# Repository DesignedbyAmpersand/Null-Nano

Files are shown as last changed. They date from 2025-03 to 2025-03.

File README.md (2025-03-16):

The Null Nano is an ESP32 powered gaming handheld that uses retro-go from ducalex.

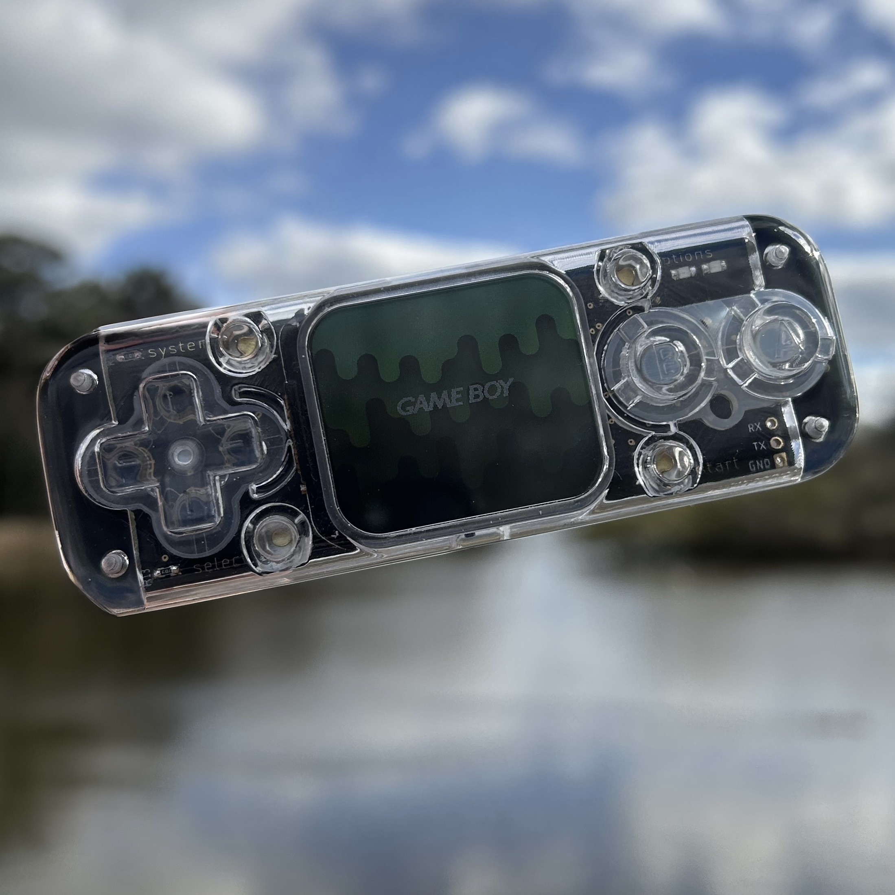
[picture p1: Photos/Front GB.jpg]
Front GB


It measures 100x35x15mm and has roughly 3 hours of battery life.

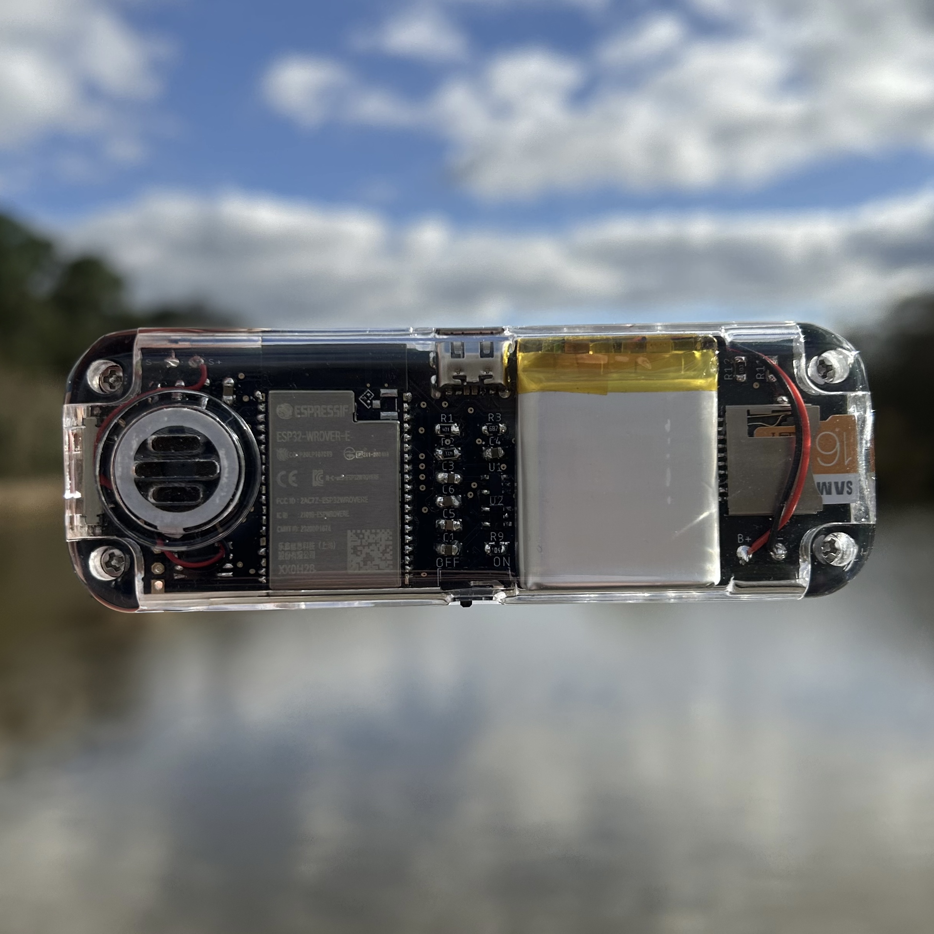
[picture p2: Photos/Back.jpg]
Back


This is not a beginner project.

These files are provided for free and with no guarantees.
These files are provided for personal use and not for resale purposes.

You will need the SD card skeleton files from here: https://1drv.ms/u/c/66cb300826c22fa3/Efv0uc86yZ5Hv4n83UHvBrcBqe-35vOahgP56gvEnUvf-g?e=ifL2Ww

You will also need the ESP32 flash download tool: https://1drv.ms/u/c/66cb300826c22fa3/EbNSYC88lTlOn8YUjpB1ucgBnk_qerDjQeKToj3xAFp3lw?e=woOXxG

Do not use a USB C to USB C cable to charge the Null Nano, it does not have anything connected to CC1 or CC2.

Do not use the Null Nano whilst charging, it does not have the necessary components to make this safe.

Use Kapton tape, do not use regular tape or masking tape.

You will need the latest version of the ESP flash tool to flash the Null Nano. Make sure you have installed the necessary drivers for your USB to UART adapter. The "options" button acts as a Boot button, so hold down options when you turn it on/provide power to enter bootloader mode for flashing.

The R3 resistor determines the charge rate. 1000/X = Y
e.g. for a 5.6K resistor the equation is 1000/5.6 = 179mA
If you use a different battery, you will need to change this resistor value.

The green LED goes on the right and the red LED on the left.

Trim the plastic pins off the bottom of the micro SD card socket with a scalpel or flush cutters (the holes needed would've interfered with the DPad).

The PCB needs to be 1.6mm thick. I order through JLCPCB and have "JLCJLCJLCJLC" written on the board so that the production number can be hidden below the ESP32.

The screws used are 8mm M2 self-tapping cap head

Resources used:

Odroid GO schematic
https://github.com/hardkernel/ODROID-GO/blob/master/Documents/ODROID-GO_REV0.1_20180518.pdf

Screen config file from this project
https://circuitdigest.com/microcontroller-projects/esp32-based-retro-game-console

Amp circuit based on Adafruit Class D amplifier
https://learn.adafruit.com/adafruit-pam8302-mono-2-5w-class-d-audio-amplifier

Charge circuit based on Adafruit MicroLiPo
https://learn.adafruit.com/adafruit-microlipo-and-minilipo-battery-chargers

Retro-go software
https://github.com/ducalex/retro-go

All graphics designed by me
The working title was "Wrigley" if you were wondering.

Let me know if you make one, have fun!
Ampersand

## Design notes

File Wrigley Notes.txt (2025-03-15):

Wrigley Notes

Wrigley is an ESP32 powered gaming handheld that uses retro-go from ducalex.
It measures 100x35x15mm and has roughly 3 hours of battery life.

This is not a beginner project.

These files are provided for free and with no guarantees.
These files are provided for personal use and not for resale purposes.

Do not use a USB C to USB C cable to charge Wrigley, it does not have anything connected to CC1 or CC2.

Do not use Wrigley whilst charging, it does not have the necessary components to make this safe.

Use Kapton tape, do not use regular tape or masking tape.

You will need the latest version of the ESP flash tool to flash Wrigley. Make sure you have installed the necessary drivers for your USB to UART adapter. The "options" button acts as a Boot button, so hold down options when you turn it on/provide power to enter bootloader mode for flashing.

The R3 resistor determines the charge rate. 1000/X = Y
e.g. for a 5.6K resistor the equation is 1000/5.6 = 179mA
If you use a different battery, you will need to change this resistor value.

The green LED goes on the right and the red LED on the left.

Trim the plastic pins off the bottom of the micro SD card socket with a scalpel or flush cutters (the holes needed would've interfered with the DPad).

The PCB needs to be 1.6mm thick. I order through JLCPCB and have "JLCJLCJLCJLC" written on the board so that the production number can be hidden below the ESP32.

The screws used are 8mm M2 self-tapping cap head

Resources used:

Odroid GO schematic
https://github.com/hardkernel/ODROID-GO/blob/master/Documents/ODROID-GO_REV0.1_20180518.pdf

Screen config file from this project
https://circuitdigest.com/microcontroller-projects/esp32-based-retro-game-console

Amp circuit based on Adafruit Class D amplifier
https://learn.adafruit.com/adafruit-pam8302-mono-2-5w-class-d-audio-amplifier

Charge circuit based on Adafruit MicroLiPo
https://learn.adafruit.com/adafruit-microlipo-and-minilipo-battery-chargers

Retro-go software
https://github.com/ducalex/retro-go

All graphics designed by me

Let me know if you make one, have fun!
Ampersand

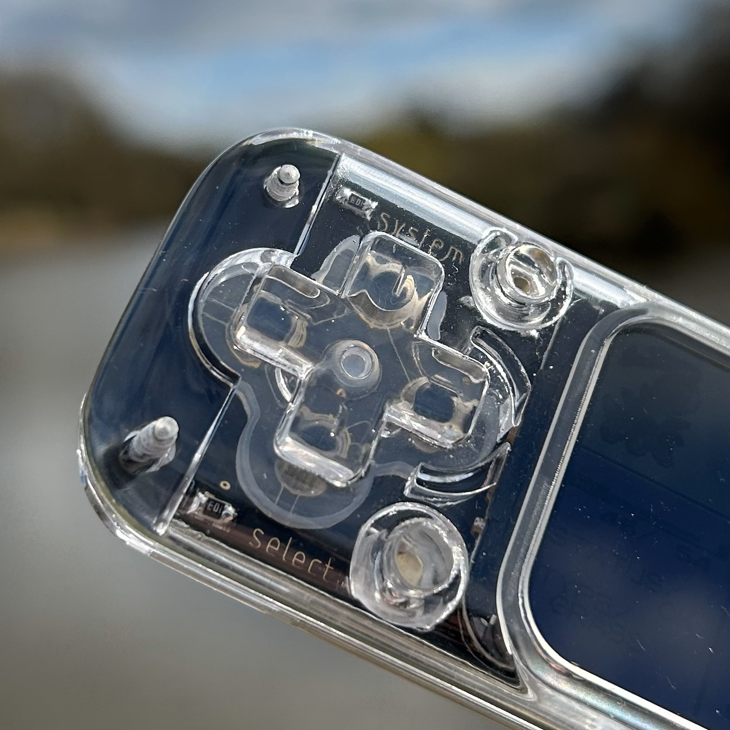
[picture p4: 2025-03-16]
Photos/Close up left.png

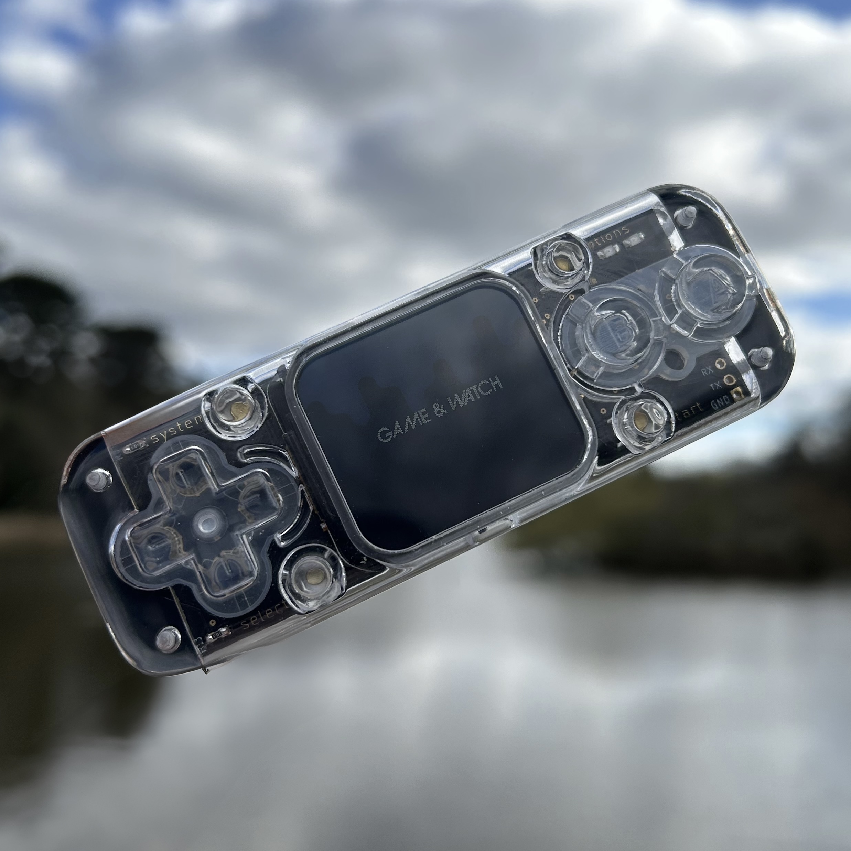
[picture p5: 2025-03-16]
Photos/Front GW.jpg

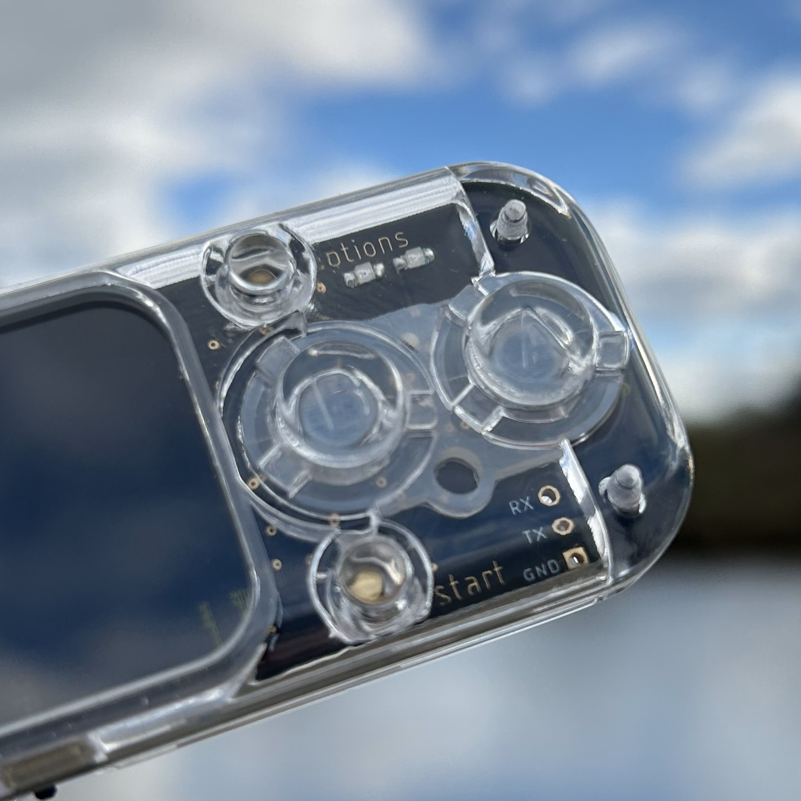
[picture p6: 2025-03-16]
Photos/Close up right.png

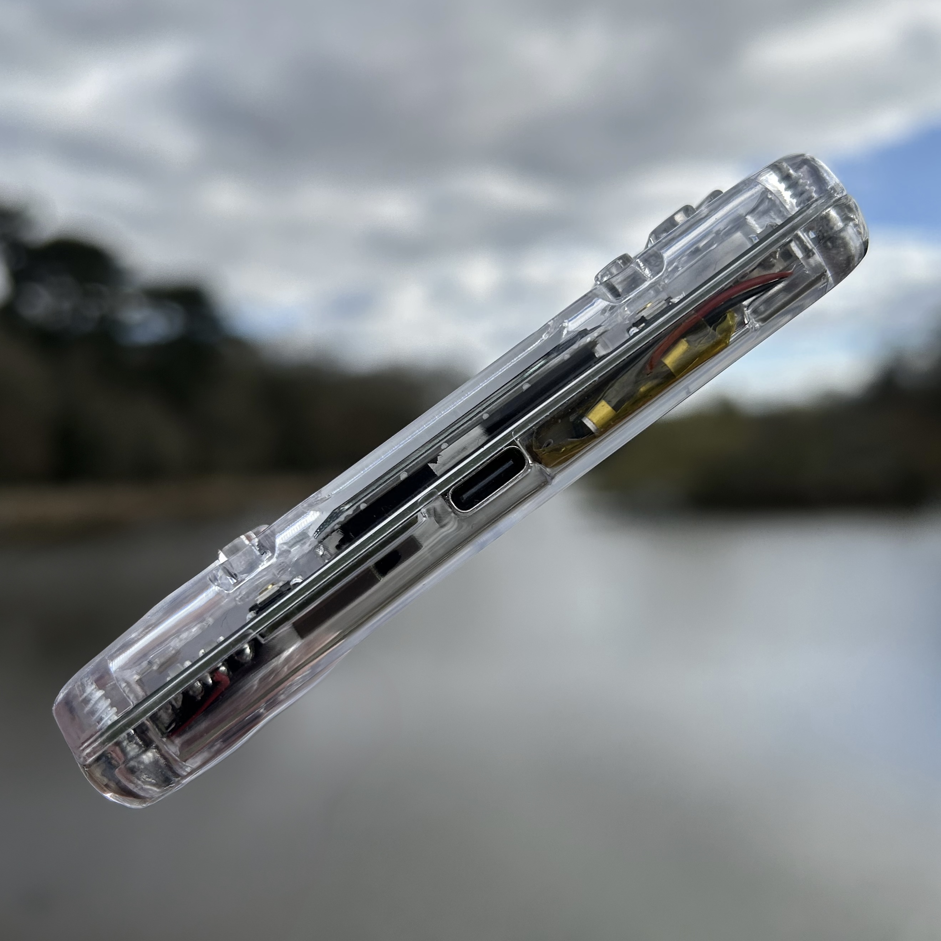
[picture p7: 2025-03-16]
Photos/Top.jpg

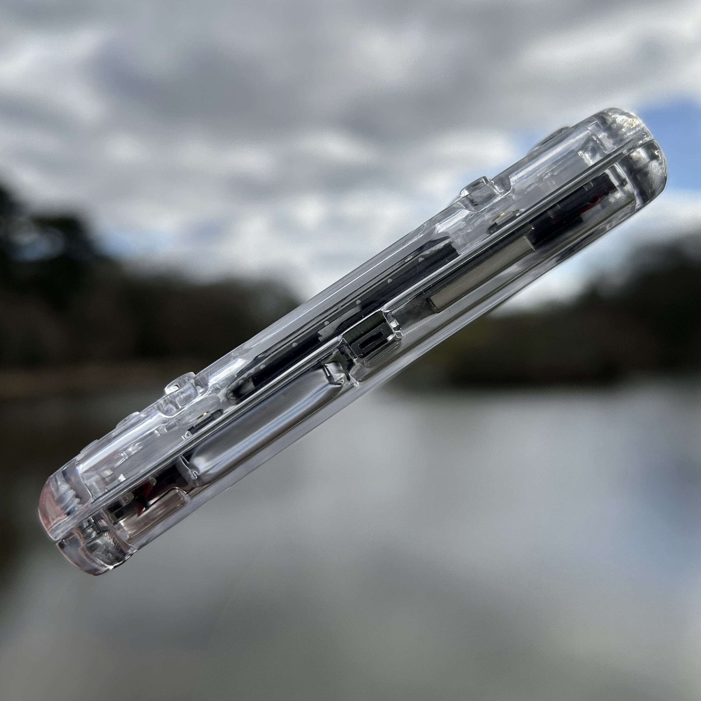
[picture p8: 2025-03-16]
Photos/Bottom.jpg

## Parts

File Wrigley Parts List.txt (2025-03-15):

Wrigley Parts List

These links will eventually stop working and may not be the cheapest place to find each component.

10uF 0805 SMD Capacitor x 5
1uF 0805 SMD Capacitor x 3
0.1uF 0805 SMD Capacitor x 3
220pF 0805 SMD Capacitor x 2
	https://www.aliexpress.com/item/32964553793.html

470R 0805 SMD Resistor x 2
5.6K 0805 SMD Resistor x 1
100K 0805 SMD Resistor x 3
10K 0805 SMD Resistor x 9
10R 0805 SMD Resistor x 1
1K 0805 SMD Resistor x 1
100R 0805 SMD Resistor x 2
	https://www.aliexpress.com/item/32865947306.html

600ohm 0805 SMD Ferrite Bead x 2
	https://www.aliexpress.com/item/1005003124199167.html

Red 0805 SMD LED x 1
	https://www.aliexpress.com/item/1005005226854182.html

Green 0805 SMD LED x 1
	https://www.aliexpress.com/item/1005005226854182.html

SOP-8 PAM8302A Audio Amplifier
	https://www.aliexpress.com/item/1005006033828553.html

AP2112 SMD Voltage Regulator
	https://www.aliexpress.com/item/32998839398.html

MCP73831/OT SMD Charge IC
	https://www.aliexpress.com/item/1005006809469170.html

S8050 J3Y SMD Transistor
	https://www.aliexpress.com/item/1005006307277263.html

15mm Speaker x 1
	https://www.aliexpress.com/item/4000069925246.html

RS08U11AZ001 10K Sliding Potentiometer x 1
	https://www.aliexpress.com/item/1005003068728711.html

ESP32 WROVER E 16MB Flash x 1
	https://www.aliexpress.com/item/1005005282692598.html

6-pin USB C socket x 1
	https://www.aliexpress.com/item/1005007079016649.html

Power Switch x 1
	https://www.aliexpress.com/item/32758858821.html

Micro SD Card Socket x 1
	https://www.aliexpress.com/item/1005006210048232.html

16GB/32GB Micro SD Card x 1
	Amazon/eBay/your cable drawer

370mAh 502530 LiPo Battery x 1
	https://www.aliexpress.com/item/32879273117.html

DS Lite D Pad Rubber Membrane x 1
	https://www.aliexpress.com/item/1005006274193598.html

Gameboy Pocket AB Rubber Membrane x 1
	https://www.aliexpress.com/item/32880941497.html

Tactile SMD Momentary Buttons 1.5mm Tall x 4
	https://www.aliexpress.com/item/10000056308274.html

1.69" ST7789V Screen with Rounded Corners x 1
	https://www.aliexpress.com/item/1005004819147206.html

1.6mm Custom PCB x 1
	https://jlcpcb.com/

USB to UART Serial Module x 1
	https://www.aliexpress.com/item/1005006445462581.html

3D Printed Case & Parts x 1
	https://www.pcbway.com/rapid-prototyping

8mm long M2 self-tapping screws x 4

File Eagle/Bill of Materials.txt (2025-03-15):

Part   Value                            Device                            Package                  Description
C1     10uF                             C-EUC0805                         C0805                    CAPACITOR
C2     10uF                             C-EUC0805                         C0805                    CAPACITOR
C3     10uF                             C-EUC0805                         C0805                    CAPACITOR
C4     10uF                             C-EUC0805                         C0805                    CAPACITOR
C5     1uF                              C-EUC0805                         C0805                    CAPACITOR
C6     0.1uF                            C-EUC0805                         C0805                    CAPACITOR
C7     0.1uF                            C-EUC0805                         C0805                    CAPACITOR
C8     0.1uF                            C-EUC0805                         C0805                    CAPACITOR
C9     1uF                              C-EUC0805                         C0805                    CAPACITOR
C10    1uF                              C-EUC0805                         C0805                    CAPACITOR
C11    10uF                             C-EUC0805                         C0805                    CAPACITOR
C12    220pF                            C-EUC0805                         C0805                    CAPACITOR
C13    220pF                            C-EUC0805                         C0805                    CAPACITOR
FB1    FBFB0805                         FBFB0805                          0805                     Ferrite bead                                                                                                  
FB2    FBFB0805                         FBFB0805                          0805                     Ferrite bead                                                                                                  
LED1   green                            LEDCHIP-LED0805                   CHIP-LED0805             The LED on the left
LED2   red                              LEDCHIP-LED0805                   CHIP-LED0805             The LED on the right
R1     470                              R-EU_R0805                        R0805                    RESISTOR, European symbol                                                                                     
R2     470                              R-EU_R0805                        R0805                    RESISTOR, European symbol                                                                                     
R3     5.6K                             R-EU_R0805                        R0805                    RESISTOR, European symbol                                                                                     
R4     100K                             R-EU_M0805                        M0805                    RESISTOR, European symbol                                                                                     
R5     100K                             R-EU_M0805                        M0805                    RESISTOR, European symbol                                                                                     
R6     10K                              R-EU_M0805                        M0805                    RESISTOR, European symbol                                                                                     
R7     10K                              R-EU_M0805                        M0805                    RESISTOR, European symbol                                                                                     
R8     10K                              R-EU_M0805                        M0805                    RESISTOR, European symbol                                                                                     
R9     100K                             R-EU_M0805                        M0805                    RESISTOR, European symbol                                                                                     
R10    10K                              R-EU_M0805                        M0805                    RESISTOR, European symbol                                                                                     
R11    10K                              R-EU_M0805                        M0805                    RESISTOR, European symbol                                                                                     
R12    10K                              R-EU_M0805                        M0805                    RESISTOR, European symbol                                                                                     
R13    10K                              R-EU_M0805                        M0805                    RESISTOR, European symbol                                                                                     
R14    10R                              R-EU_M0805                        M0805                    RESISTOR, European symbol                                                                                     
R15    10K                              R-EU_M0805                        M0805                    RESISTOR, European symbol                                                                                     
R16    1K                               R-EU_M0805                        M0805                    RESISTOR, European symbol                                                                                     
R18    100R                             R-EU_R0805                        R0805                    RESISTOR, European symbol
R19    100R                             R-EU_R0805                        R0805                    RESISTOR, European symbol
R20    10K                              R-EU_R0805                        R0805                    RESISTOR, European symbol
T1     S8050                            S8050                             SOT23-BEC                                                                                                                              
U1     MCP73831/OT                      MCP73831/OT                       SOT23-5L                 MCP73831/2                                                                                                    
U2     AP2112-REGULATOR                 AP2112-REGULATOR                  SOT23-5L                                                                                                                               
U3     PAM8302A                         PAM8302A                          SOP8

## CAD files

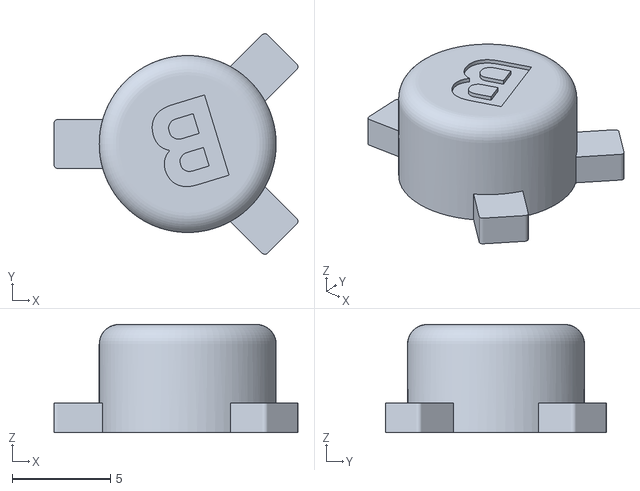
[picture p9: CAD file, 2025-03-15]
3D Printable Case/Wrigley B button.STL
12.4 x 11.2 x 5.50

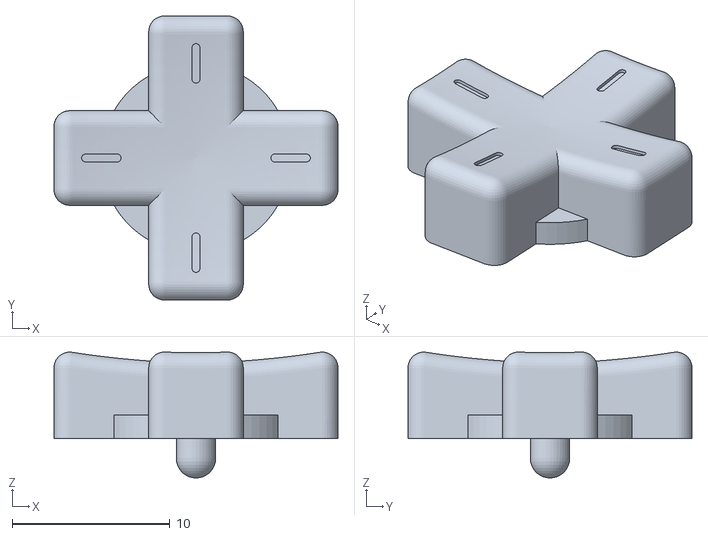
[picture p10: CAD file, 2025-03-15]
3D Printable Case/Wrigley Dpad Long.STL
18.0 x 18.0 x 7.98

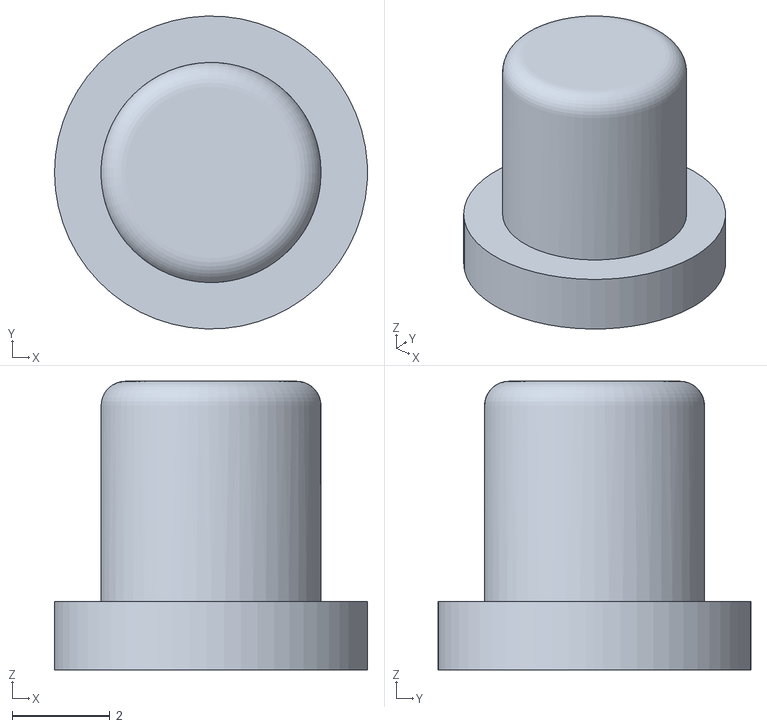
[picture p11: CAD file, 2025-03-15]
3D Printable Case/Wrigley Menu Button 3.STL
6.40 x 6.40 x 5.90

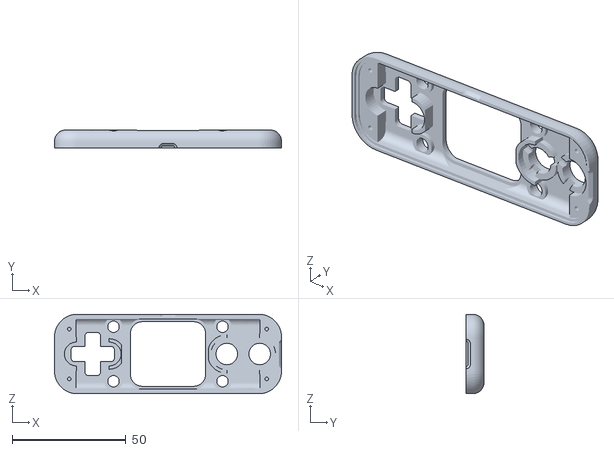
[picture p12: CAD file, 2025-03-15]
3D Printable Case/Wrigley Top.STL
100.0 x 8.00 x 35.0

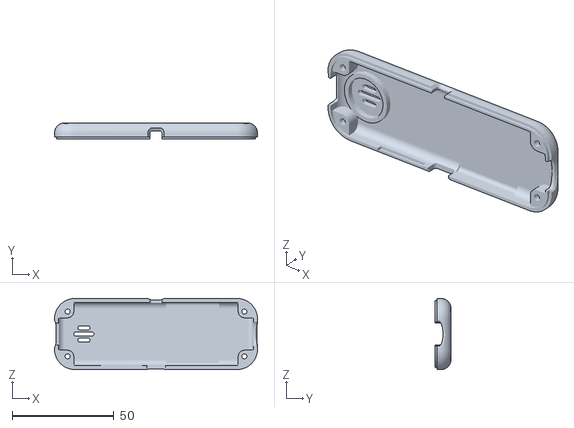
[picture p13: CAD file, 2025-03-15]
3D Printable Case/Wrigley Bottom.STL
100.0 x 8.00 x 35.0

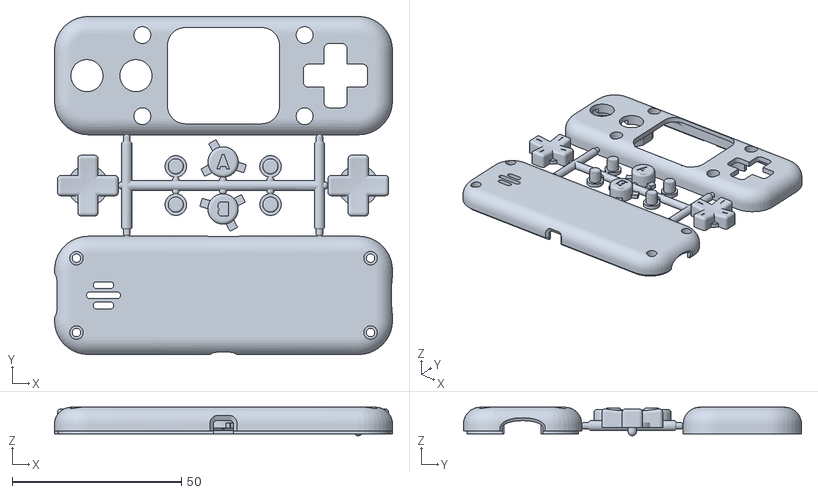
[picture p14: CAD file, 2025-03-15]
3D Printable Case/Wrigley All on Sprue.STL
100.0 x 100.0 x 8.48

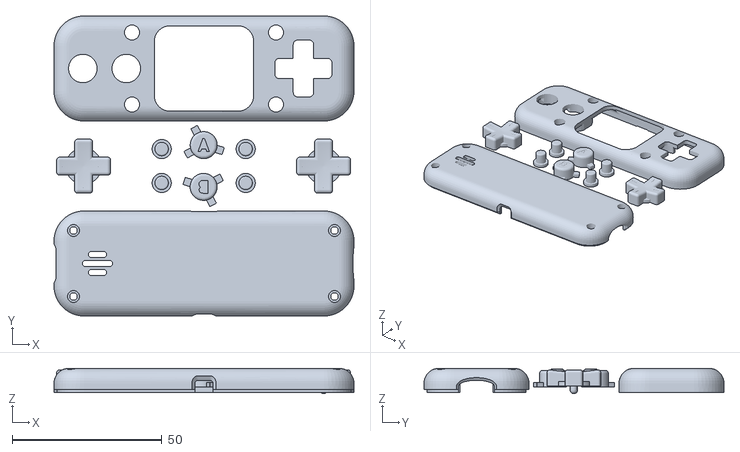
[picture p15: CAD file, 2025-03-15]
3D Printable Case/Wrigley All No Sprue.STL
100.0 x 100.0 x 8.48

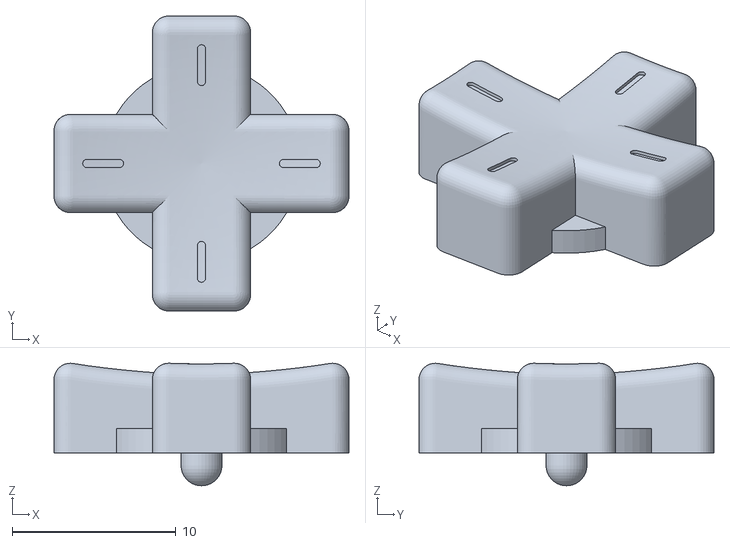
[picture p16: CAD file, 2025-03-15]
3D Printable Case/Wrigley Dpad.STL
18.0 x 18.0 x 7.48

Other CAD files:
3D Printable Case/Wrigley A button.STL

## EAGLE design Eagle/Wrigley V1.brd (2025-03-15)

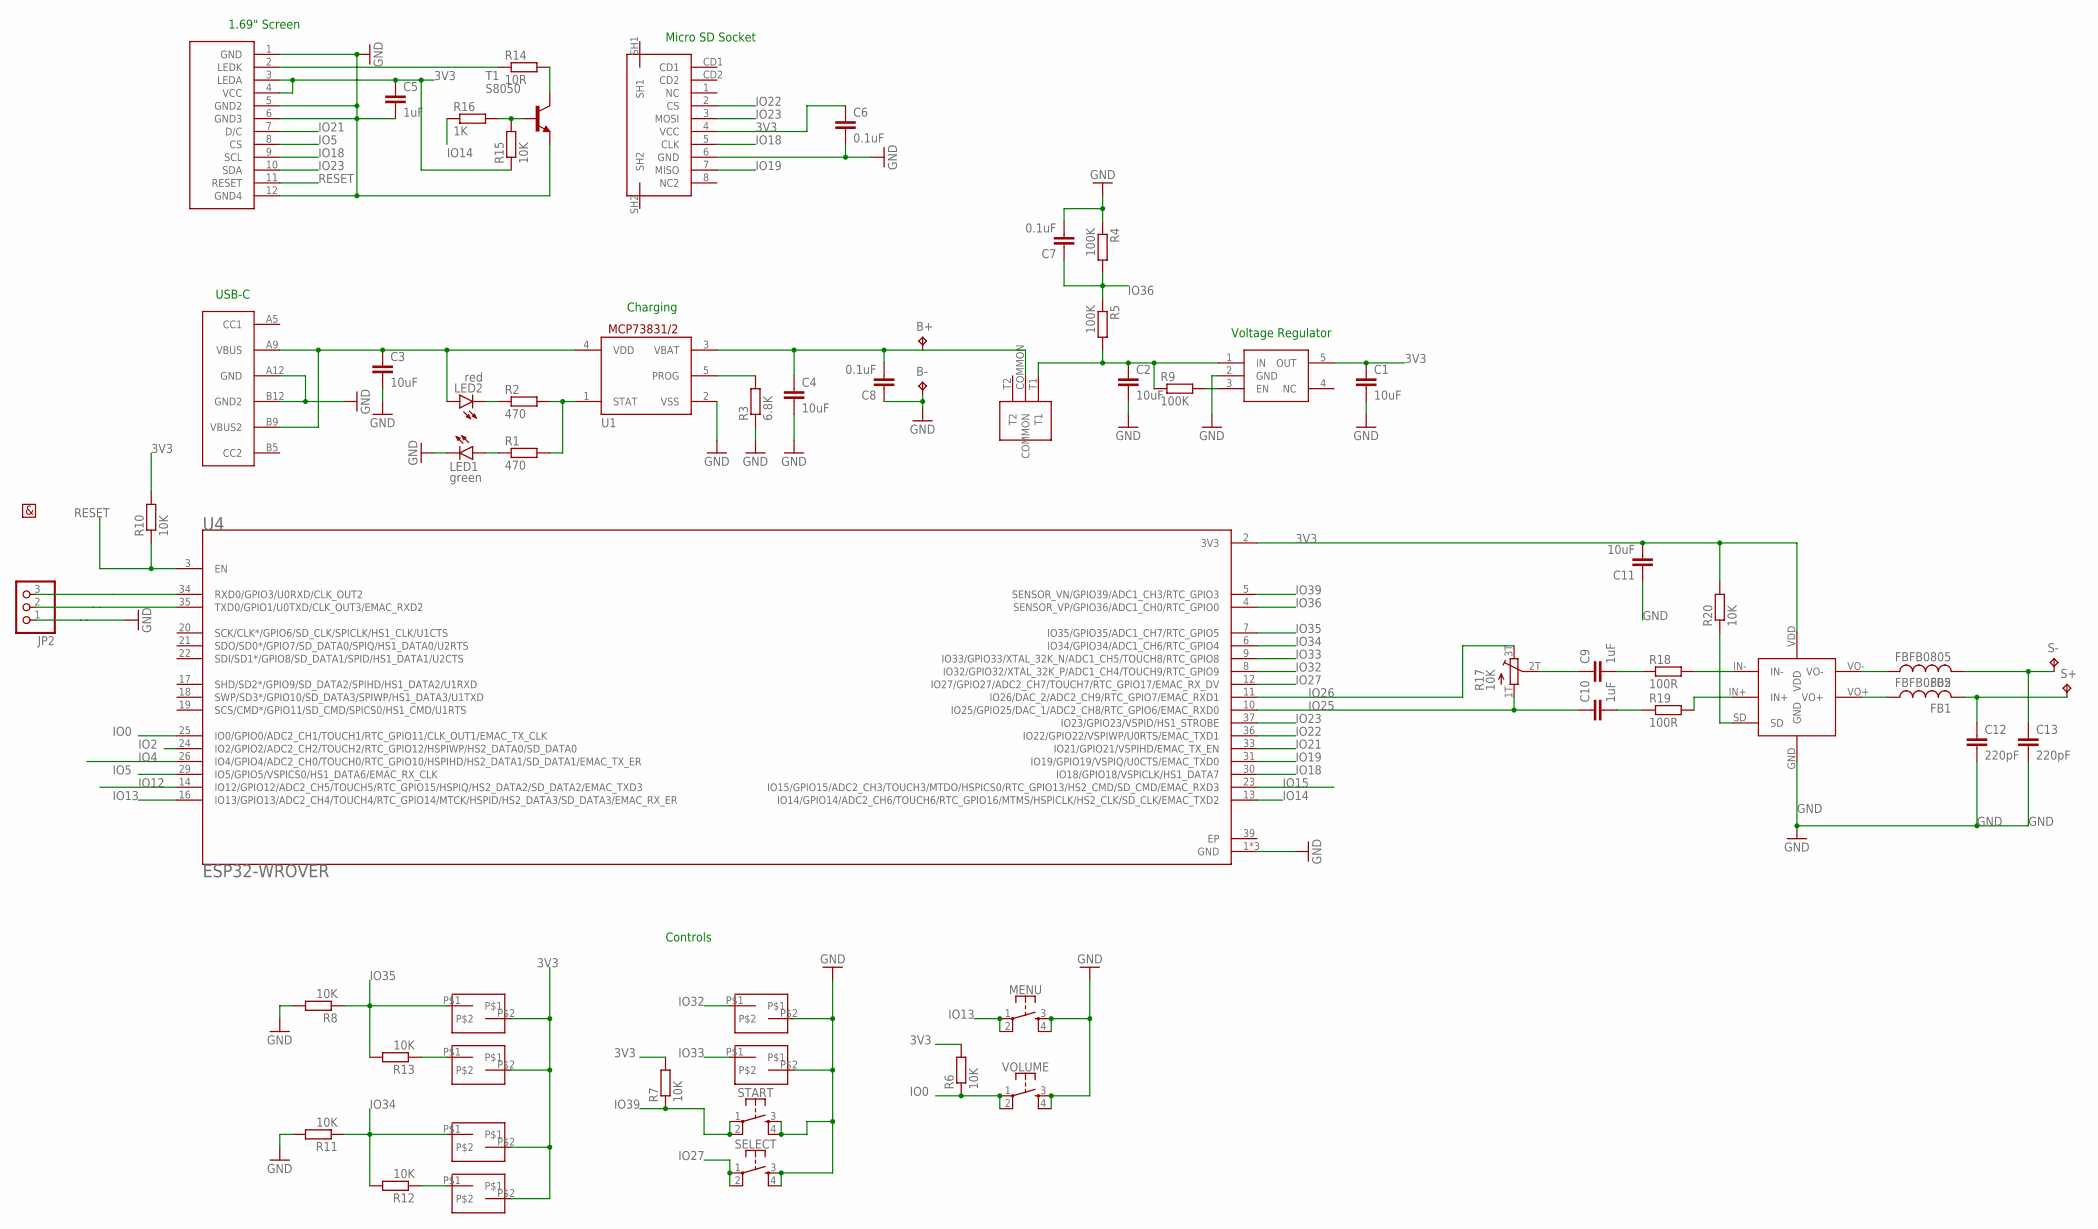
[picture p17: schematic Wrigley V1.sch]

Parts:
A: POCKET-BUTTONS-BIG; POCKET-MEMBRANE-BIG
B: POCKET-BUTTONS-BIG; POCKET-MEMBRANE-BIG
B+: TPTP20R; TP20R
B-: TPTP20R; TP20R
C1, C2, C3, C4, C11: 10uF; C0805
C5, C9, C10: 1uF; C0805
C6, C7, C8: 0.1uF; C0805
C12, C13: 220pF; C0805
DOWN: POCKET-BUTTONS-BIG; POCKET-MEMBRANE-BIG
FB1, FB2: FBFB0805; 0805
JP2: PINHD-1X03_2.54-S; 1X03-S
LED1: green; CHIP-LED0805
LED2: red; CHIP-LED0805
LEFT: POCKET-BUTTONS-BIG; POCKET-MEMBRANE-BIG
MENU: MOMENTARY-SWITCH-SPST-2-SMD-5.2MM; TACTILE_SWITCH_SMD_5.2MM
R1, R2: 470; R0805
R3: 6.8K; R0805
R4, R5, R9: 100K; M0805
R6, R7, R8, R10, R11, R12, R13, R15: 10K; M0805
R14: 10R; M0805
R16: 1K; M0805
R17: 10K; SLIDE-POT-RS08U11AZ001
R18, R19: 100R; R0805
R20: 10K; R0805
RIGHT: POCKET-BUTTONS-BIG; POCKET-MEMBRANE-BIG
S+: TPTP20R; TP20R
S-: TPTP20R; TP20R
SELECT: MOMENTARY-SWITCH-SPST-2-SMD-5.2MM; TACTILE_SWITCH_SMD_5.2MM
START: MOMENTARY-SWITCH-SPST-2-SMD-5.2MM; TACTILE_SWITCH_SMD_5.2MM
T1: S8050; SOT23-BEC
U1: MCP73831/OT; SOT23-5L
U2: AP2112-REGULATORWRIGLEY; SOT23-5L
U3: PAM8302A; PAM8302A-SOP8
U4: ESP32-WROVER; XCVR-ESP32-WROVER
U$1: MICROSD-SOCKET-RISTRETTONO-HOLES; MICROSD-SOCKET-WRIGLEY
U$3: 1.69-INCH-SCREEN-ROUNDED
U$5: NULL2-SWITCH
U$8: USB-C-6PIN
U$9: AMP-HALF
UP: POCKET-BUTTONS-BIG; POCKET-MEMBRANE-BIG
VOLUME: MOMENTARY-SWITCH-SPST-2-SMD-5.2MM; TACTILE_SWITCH_SMD_5.2MM

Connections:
3V3: C1.1, C5.1, C6.1, C11.2, DOWN.P$2, LEFT.P$2, R6.2, R7.2, R10.2, R15.1, R20.2, RIGHT.P$2, U2.5 (OUT), U3.VDD, U4.2 (3V3), U$1.4 (VCC), U$3.3 (LEDA), U$3.4 (VCC), UP.P$2
EP: U4.39 (EP)
GND: A.P$2, B.P$2, B-.TP, C1.2, C2.2, C3.2, C4.2, C5.2, C6.2, C7.2, C8.1, C11.1, C12.2, C13.2, JP2.1, LED1.C, MENU.3, MENU.4, R3.1, R4.1, R8.2, R11.2, SELECT.3, SELECT.4, START.3, START.4, T1.E, U1.2 (VSS), U2.2 (GND), U3.GND, U4.1 (GND), U4.15 (GND), U4.38 (GND), U$1.6 (GND), U$3.1 (GND), U$3.5 (GND2), U$3.6 (GND3), U$3.12 (GND4), U$8.A12 (GND), U$8.B12 (GND2), VOLUME.3, VOLUME.4
IO0: R6.1, U4.25 (IO0/GPIO0/ADC2_CH1/TOUCH1/RTC_GPIO11/CL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), VOLUME.1, VOLUME.2
IO2: U4.24 (IO2/GPIO2/ADC2_CH2/TOUCH2/RTC_GPIO12/HS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)
IO4: U4.26 (IO4/GPIO4/ADC2_CH0/TOUCH0/RTC_GPIO10/HS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)
IO5: U4.29 (IO5/GPIO5/VSPICS0/HS1_DATA6/EMAC_RX_CLK), U$3.8 (CS)
IO12: U4.14 (IO12/GPIO12/ADC2_CH5/TOUCH5/RTC_GPIO15/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)
IO13: MENU.1, MENU.2, U4.16 (IO13/GPIO13/ADC2_CH4/TOUCH4/RTC_GPIO14/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)
IO14: R16.1, U4.13 (IO14/GPIO14/ADC2_CH6/TOUCH6/RTC_GPIO16/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)
IO15: U4.23 (IO15/GPIO15/ADC2_CH3/TOUCH3/MTDO/HSPICS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)
IO18: U4.30 (IO18/GPIO18/VSPICLK/HS1_DATA7), U$1.5 (CLK), U$3.9 (SCL)
IO19: U4.31 (IO19/GPIO19/VSPIQ/U0CTS/EMAC_TXD0), U$1.7 (MISO)
IO21: U4.33 (IO21/GPIO21/VSPIHD/EMAC_TX_EN), U$3.7 (D/C)
IO22: U4.36 (IO22/GPIO22/VSPIWP/U0RTS/EMAC_TXD1), U$1.2 (CS)
IO23: U4.37 (IO23/GPIO23/VSPID/HS1_STROBE), U$1.3 (MOSI), U$3.10 (SDA)
IO25: C10.1, R17.1T (1), U4.10 (IO25/GPIO25/DAC_1/ADC2_CH8/RTC_GPIO6/EM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)
IO26: R17.3T (3), U4.11 (IO26/DAC_2/ADC2_CH9/RTC_GPIO7/EMAC_RXD1)
IO27: SELECT.1, SELECT.2, U4.12 (IO27/GPIO27/ADC2_CH7/TOUCH7/RTC_GPIO17/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)
IO32: A.P$1, U4.8 (IO32/GPIO32/XTAL_32K_P/ADC1_CH4/TOUCH9/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)
IO33: B.P$1, U4.9 (IO33/GPIO33/XTAL_32K_N/ADC1_CH5/TOUCH8/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)
IO34: LEFT.P$1, R11.1, R12.2, U4.6 (IO34/GPIO34/ADC1_CH6/RTC_GPIO4)
IO35: R8.1, R13.2, U4.7 (IO35/GPIO35/ADC1_CH7/RTC_GPIO5), UP.P$1
IO36: C7.1, R4.2, R5.1, U4.4 (SENSOR_VP/GPIO36/ADC1_CH0/RTC_GPIO0)
IO39: R7.1, START.1, START.2, U4.5 (SENSOR_VN/GPIO39/ADC1_CH3/RTC_GPIO3)
unnamed: R9.2, U2.3 (EN)
unnamed: C2.1, R5.2, R9.1, U2.1 (IN), U$5.T1
unnamed: R3.2, U1.5 (PROG)
unnamed: R1.2, R2.2, U1.1 (STAT)
unnamed: LED2.C, R2.1
unnamed: LED1.A, R1.1
unnamed: DOWN.P$1, R13.1
unnamed: C3.1, LED2.A, U1.4 (VDD), U$8.A9 (VBUS), U$8.B9 (VBUS2)
unnamed: B+.TP, C4.1, C8.2, U1.3 (VBAT), U$5.COMMON
unnamed: R14.1, U$3.2 (LEDK)
unnamed: JP2.3, U4.34 (RXD0/GPIO3/U0RXD/CLK_OUT2)
unnamed: JP2.2, U4.35 (TXD0/GPIO1/U0TXD/CLK_OUT3/EMAC_RXD2)
unnamed: R14.2, T1.C
unnamed: R15.2, R16.2, T1.B
unnamed: R12.1, RIGHT.P$1
unnamed: C9.1, R17.2T (2)
unnamed: C9.2, R18.1
unnamed: C10.2, R19.1
unnamed: R18.2, U3.IN-
unnamed: R19.2, U3.IN+
unnamed: C13.1, FB2.2, S-.TP
unnamed: C12.1, FB1.2, S+.TP
unnamed: FB2.1, U3.VO-
unnamed: FB1.1, U3.VO+
unnamed: R20.1, U3.SD
RESET: R10.1, U4.3 (EN), U$3.11 (RESET)

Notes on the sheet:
USB-C
Charging
Voltage Regulator
Controls
Micro SD Socket
1.69" Screen

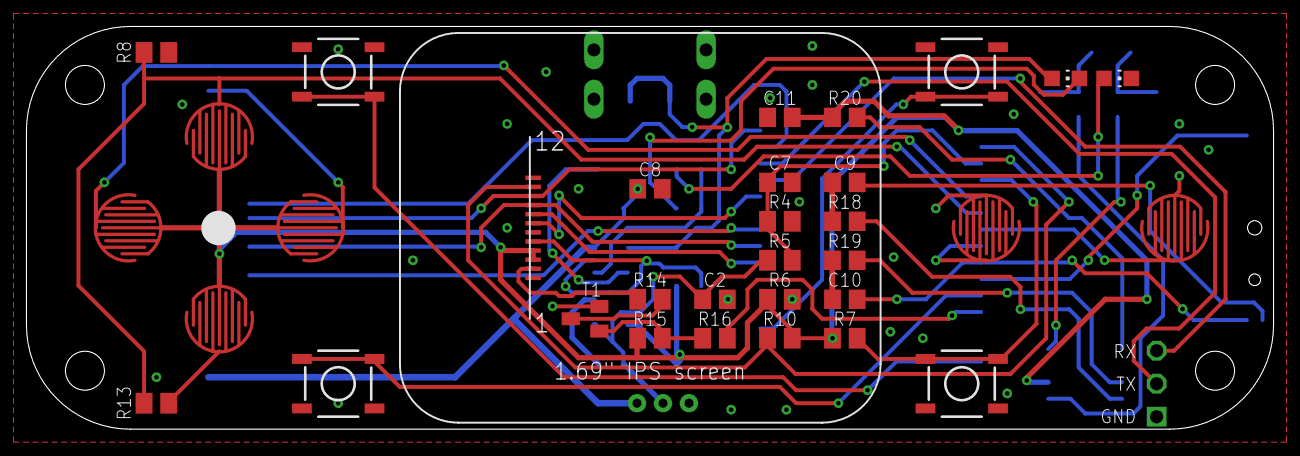
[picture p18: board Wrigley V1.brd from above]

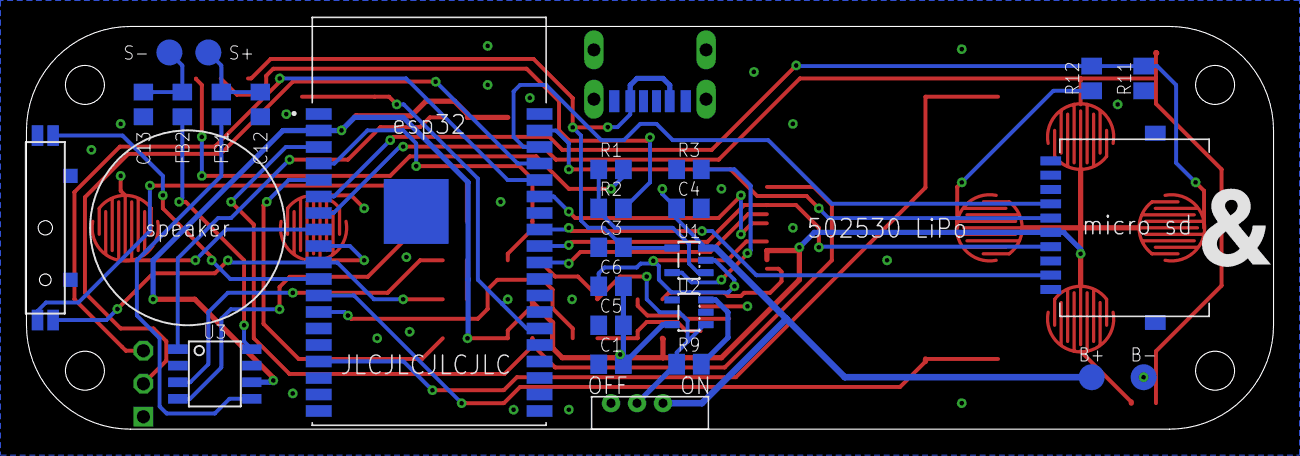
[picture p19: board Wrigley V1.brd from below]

Board: 2 copper layers, 96.0 x 31.0 mm, 62 parts (28 on the bottom side), 46 nets.
